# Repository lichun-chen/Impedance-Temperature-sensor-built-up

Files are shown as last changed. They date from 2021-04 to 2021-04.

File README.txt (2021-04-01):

//This project is the Final version code used in Z_T_sensor
The Z_T_sensor is designed to monitor the impedance and temperature of mortar samples installed in the field environments. Several multiplers, a real-time colock, a SD card is embaded into this circuit to get the real-time reading of the field samples.
License
OSU GENERAL PUBLIC LICENSE V1.0

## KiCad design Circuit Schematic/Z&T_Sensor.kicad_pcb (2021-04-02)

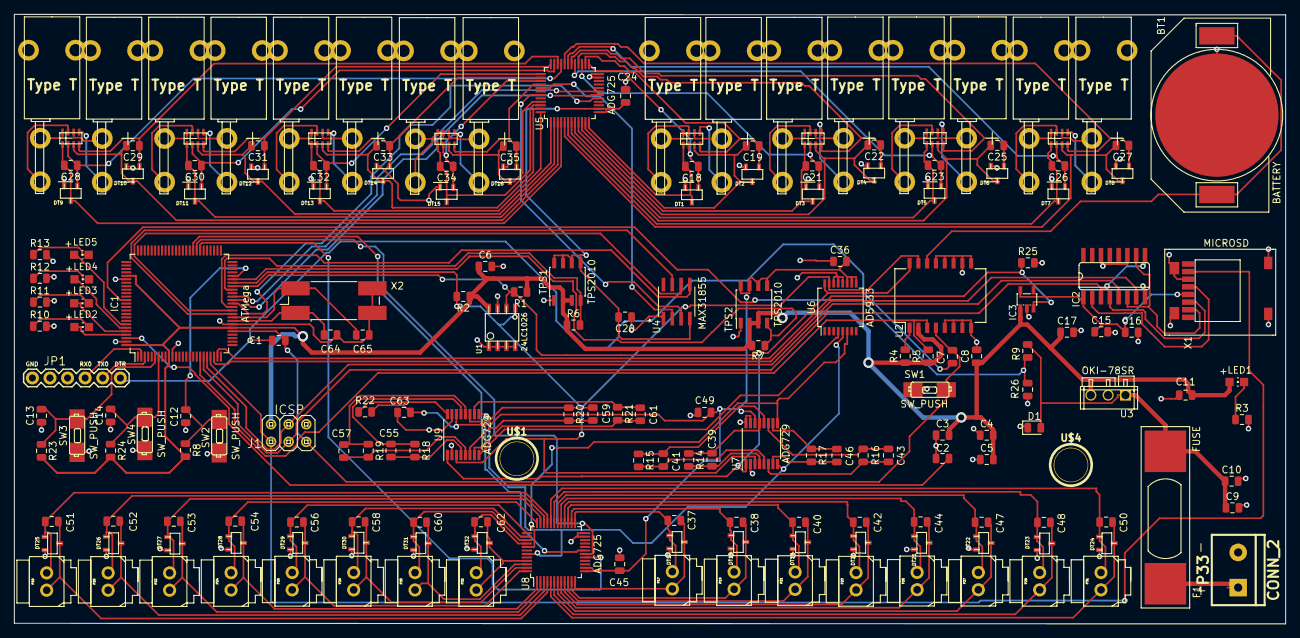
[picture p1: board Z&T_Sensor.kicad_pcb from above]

Board: 2 copper layers, 183.6 x 88.0 mm, 196 parts (0 on the bottom side), 169 nets.

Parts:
BT1: BATTERY; Battery_20mm_coincell
C1, C2, C3, C4, C5, C6, C7, C8, C12, C13, C14, C15, C17: 0.1uF; C_0805_2012Metric
C9: 10u; C_0805_2012Metric
C10, C11: 0.1u; C_0805_2012Metric
C16: 10uF; C_0805_2012Metric
C18, C19, C20, C21, C22, C23, C24, C25, C26, C27, C28, C29, C30, C31, C32, C33, C34, C35, C36, C37, C38, C39, C40, C41, C42, C43, C44, C45, C46, C47, C48, C49, C50, C51, C52, C53, C54, C55, C56, C57, C58, C59, C60, C61, C62, C63: .01uF; C_0805_2012Metric
C64, C65: 22pF; C_0805_2012Metric
D1: DIODE; D_0805_2012Metric
DT1, DT2, DT3, DT4, DT5, DT6, DT7, DT8, DT9, DT10, DT11, DT12, DT13, DT14, DT15, DT16, DT17, DT18, DT19, DT20, DT21, DT22, DT23, DT24, DT25, DT26, DT27, DT28, DT29, DT30, DT31, DT32: TVSARRAY
F1: FUSE; FUSE_5x25
FB1, FB2, FB3, FB4, FB5, FB6, FB7, FB8: FEARRAY
IC1: ATMEGA2560-A; ATMega_TQFP-100_14x14mm_P0.5mm
IC2: 4050D; SO16
IC3: LP298XS; SOT23-5L
J1: ICSP; ICSP-pinhead-1-2X03
JP1: FTDI Basic; 1X06
LED1, LED2, LED3, LED4, LED5: LED; CHIP-LED0805
P1, P2, P3, P4, P5, P6, P7, P8, P9, P10, P11, P12, P13, P14, P15, P16: CONN_4; thermocouple-connector
P17, P18, P19, P20, P21, P22, P23, P24, P25, P26, P27, P28, P29, P30, P31, P32: CONN_2; Z_COMBICON2
P33: CONN_2; bornier2_V
R1, R2, R22, R26: 10K; R_0805_2012Metric
R3, R4, R5, R10, R11, R12, R13: 330; R_0805_2012Metric
R6, R7, R25: 100K; R_0805_2012Metric
R8, R9, R23, R24: 47k; R_0805_2012Metric
R14, R18: 560; R_0805_2012Metric
R15, R19: 1000; R_0805_2012Metric
R16, R20: 1500; R_0805_2012Metric
R17, R21: 2000; R_0805_2012Metric
SW1, SW2, SW3, SW4: SW_PUSH; SWITCH_2padsmd
TPS1, TPS2: TPS2010; TPS2010_SOIC-8-N8_3.9x4.9mm_P1.27mm
U1: 24LC1026
U2: DS3231; SOIC-16W_7.5x12.8mm_P1.27mm
U3: OKI-78SR
U4: MAX31855; MAX31855TASA&plus_T
U5, U8: ADG725; ADG725_TQFP-48-1EP_7x7mm_P0.5mm_EP3.5x3.5mm
U6: AD5933; AD5933_SSOP-16_5.3x6.2mm_P0.65mm
U7, U9: ADG729; ADG729_TSSOP-16_4.4x5mm_P0.65mm
U$1, U$4: FIDUCIAL; DrillHole_1pin
X1: MICROSD; MicroSD_2
X2: CRYSTAL; Crystal_SMD_SeikoEpson_MA506-4Pin_12.7x5.1mm

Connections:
+12V: F1.1, P33.1
/MISO: IC1.22, J1.1, X1.7
/MOSI: IC1.21, IC2.5, J1.4
/RX0: IC1.2, JP1.3
/SCK: IC1.20, IC2.3, IC2.9, J1.3
/SD_CS: IC1.23, IC2.7
/SD_Card/+3V3: C15.1, C16.1, IC2.1, IC3.5, X1.4
/SD_EN: IC1.24, IC3.3, R25.1
/Switch_LED/SWITCH1: C12.2, IC1.46, R8.1, SW2.2
/Switch_LED/SWITCH2: C13.2, IC1.6, R23.1, SW3.2
/Switch_LED/SWITCH3: C14.2, IC1.7, R24.1, SW4.2
/TX0: IC1.3, JP1.2
/T_sensor/5V: C20.2, C24.1, TPS1.5, TPS1.6, TPS1.7, TPS1.8, U4.4, U5.13, U5.14
/T_sensor/DIN: IC1.39, U5.18
/T_sensor/MISO: IC1.35, U4.7
/T_sensor/SCK: IC1.37, U4.5
/T_sensor/SCLK: IC1.40, U5.19
/T_sensor/SS: IC1.36, U4.6
/T_sensor/SYNC: IC1.38, U5.17
/T_sensor/ThermocoupleBreakout/T1a: FB1.5, P1.1
/T_sensor/ThermocoupleBreakout/T1b: FB1.6, P1.2
/T_sensor/ThermocoupleBreakout/T2a: FB1.7, P3.1
/T_sensor/ThermocoupleBreakout/T2b: FB1.8, P3.2
/T_sensor/ThermocoupleBreakout/T3a: FB2.5, P5.1
/T_sensor/ThermocoupleBreakout/T3b: FB2.6, P5.2
/T_sensor/ThermocoupleBreakout/T4a: FB2.7, P7.1
/T_sensor/ThermocoupleBreakout/T4b: FB2.8, P7.2
/T_sensor/ThermocoupleBreakout/T5a: FB3.5, P9.1
/T_sensor/ThermocoupleBreakout/T5b: FB3.6, P9.2
/T_sensor/ThermocoupleBreakout/T6a: FB3.7, P11.1
/T_sensor/ThermocoupleBreakout/T6b: FB3.8, P11.2
/T_sensor/ThermocoupleBreakout/T7a: FB4.5, P13.1
/T_sensor/ThermocoupleBreakout/T7b: FB4.6, P13.2
/T_sensor/ThermocoupleBreakout/T8a: FB4.7, P15.1
/T_sensor/ThermocoupleBreakout/T8b: FB4.8, P15.2
/T_sensor/ThermocoupleBreakout/T9a: FB5.5, P2.1
/T_sensor/ThermocoupleBreakout/T9b: FB5.6, P2.2
/T_sensor/ThermocoupleBreakout/T10a: FB5.7, P4.1
/T_sensor/ThermocoupleBreakout/T10b: FB5.8, P4.2
/T_sensor/ThermocoupleBreakout/T11a: FB6.5, P6.1
/T_sensor/ThermocoupleBreakout/T11b: FB6.6, P6.2
/T_sensor/ThermocoupleBreakout/T12a: FB6.7, P8.1
/T_sensor/ThermocoupleBreakout/T12b: FB6.8, P8.2
/T_sensor/ThermocoupleBreakout/T13a: FB7.5, P10.1
/T_sensor/ThermocoupleBreakout/T13b: FB7.6, P10.2
/T_sensor/ThermocoupleBreakout/T14a: FB7.7, P12.1
/T_sensor/ThermocoupleBreakout/T14b: FB7.8, P12.2
/T_sensor/ThermocoupleBreakout/T15a: FB8.5, P14.1
/T_sensor/ThermocoupleBreakout/T15b: FB8.6, P14.2
/T_sensor/ThermocoupleBreakout/T16a: FB8.7, P16.1
/T_sensor/ThermocoupleBreakout/T16b: FB8.8, P16.2
/Z_sensor/5V: C36.2, C45.2, C49.2, C63.2, R22.2, TPS2.5, TPS2.6, TPS2.7, TPS2.8, U6.9, U6.10, U6.11, U7.14, U8.13, U8.14, U9.14
/Z_sensor/DIN: IC1.58, U8.18
/Z_sensor/SCLK: IC1.59, U8.19
/Z_sensor/SYNC: IC1.57, U8.17
/Z_sensor/z_impedance/Z1A: C37.2, DT17.2, P17.1, U8.12
/Z_sensor/z_impedance/Z1B: C37.1, DT17.1, P17.2, U8.25
/Z_sensor/z_impedance/Z2A: C38.2, DT18.2, P19.1, U8.11
/Z_sensor/z_impedance/Z2B: C38.1, DT18.1, P19.2, U8.26
/Z_sensor/z_impedance/Z3A: C40.2, DT19.2, P21.1, U8.10
/Z_sensor/z_impedance/Z3B: C40.1, DT19.1, P21.2, U8.27
/Z_sensor/z_impedance/Z4A: C42.2, DT20.2, P23.1, U8.9
/Z_sensor/z_impedance/Z4B: C42.1, DT20.1, P23.2, U8.28
/Z_sensor/z_impedance/Z5A: C44.2, DT21.2, P25.1, U8.8
/Z_sensor/z_impedance/Z5B: C44.1, DT21.1, P25.2, U8.29
/Z_sensor/z_impedance/Z6A: C47.2, DT22.2, P27.1, U8.7
/Z_sensor/z_impedance/Z6B: C47.1, DT22.1, P27.2, U8.30
/Z_sensor/z_impedance/Z7A: C48.2, DT23.2, P29.1, U8.6
/Z_sensor/z_impedance/Z7B: C48.1, DT23.1, P29.2, U8.31
/Z_sensor/z_impedance/Z8A: C50.2, DT24.2, P31.1, U8.5
/Z_sensor/z_impedance/Z8B: C50.1, DT24.1, P31.2, U8.32
/Z_sensor/z_impedance/Z9A: C51.2, DT25.2, P18.1, U8.4
/Z_sensor/z_impedance/Z9B: C51.1, DT25.1, P18.2, U8.33
/Z_sensor/z_impedance/Z10A: C52.2, DT26.2, P20.1, U8.3
/Z_sensor/z_impedance/Z10B: C52.1, DT26.1, P20.2, U8.34
/Z_sensor/z_impedance/Z11A: C53.2, DT27.2, P22.1, U8.2
/Z_sensor/z_impedance/Z11B: C53.1, DT27.1, P22.2, U8.35
/Z_sensor/z_impedance/Z12A: C54.2, DT28.2, P24.1, U8.1
/Z_sensor/z_impedance/Z12B: C54.1, DT28.1, P24.2, U8.36
/Z_sensor/z_impedance/Z13A: C56.2, DT29.2, P26.1, U8.48
/Z_sensor/z_impedance/Z13B: C56.1, DT29.1, P26.2, U8.37
/Z_sensor/z_impedance/Z14A: C58.2, DT30.2, P28.1, U8.47
/Z_sensor/z_impedance/Z14B: C58.1, DT30.1, P28.2, U8.38
/Z_sensor/z_impedance/Z15A: C60.2, DT31.2, P30.1, U8.46
/Z_sensor/z_impedance/Z15B: C60.1, DT31.1, P30.2, U8.39
/Z_sensor/z_impedance/Z16A: C62.2, DT32.2, P32.1, U8.45
/Z_sensor/z_impedance/Z16B: C62.1, DT32.1, P32.2, U8.40
/clock-ISP schema/INTSQW: IC1.19, R5.2, U2.3
/led/LED1: IC1.97, LED2.A
/led/LED2: IC1.96, LED3.A
/led/LED3: IC1.95, LED4.A
/led/LED4: IC1.94, LED5.A
ADBATT: IC1.87, R9.1, R26.2
DTR: C1.2, C7.2, JP1.1
GND: BT1.2, C2.2, C3.1, C4.1, C5.1, C6.2, C8.2, C9.2, C10.2, C11.2, C12.1, C13.1, C14.1, C15.2, C16.2, C17.2, C20.1, C24.2, C36.1, C45.1, C49.1, C63.1, C64.2, C65.2, D1.1, DT1.3, DT2.3, DT3.3, DT4.3, DT5.3, DT6.3, DT7.3, DT8.3, DT9.3, DT10.3, DT11.3, DT12.3, DT13.3, DT14.3, DT15.3, DT16.3, DT17.3, DT18.3, DT19.3, DT20.3, DT21.3, DT22.3, DT23.3, DT24.3, DT25.3, DT26.3, DT27.3, DT28.3, DT29.3, DT30.3, DT31.3, DT32.3, IC1.11, IC1.32, IC1.81, IC1.99, IC2.8, IC2.11, IC2.14, IC3.2, J1.6, JP1.6, P1.3, P1.4, P2.3, P2.4, P3.3, P3.4, P4.3, P4.4, P5.3, P5.4, P6.3, P6.4, P7.3, P7.4, P8.3, P8.4, P9.3, P9.4, P10.3, P10.4, P11.3, P11.4, P12.3, P12.4, P13.3, P13.4, P14.3, P14.4, P15.3, P15.4, P16.3, P16.4, P33.2, R3.2, R10.2, R11.2, R12.2, R13.2, R25.2, R26.1, SW1.1, SW2.1, SW3.1, SW4.1, TPS1.1, TPS2.1, U1.1, U1.2, U1.3, U1.4, U1.7, U2.5, U2.6, U2.7, U2.8, U2.9, U2.10, U2.11, U2.12, U2.13, U3.2, U4.1, U5.23, U5.24, U6.12, U6.13, U6.14, U7.2, U7.15, U7.16, U8.23, U8.24, U9.2, U9.15, X1.6, X1.GND1, X1.GND2, X1.GND3, X1.GND4, X2.2, X2.3
unnamed: BT1.1, U2.14
unnamed: C2.1, IC1.98
unnamed: C9.1, C10.1, D1.2, F1.2, R9.2, U3.1
unnamed: C18.1, DT1.1, FB1.2, U5.25
unnamed: C18.2, DT1.2, FB1.1, U5.12
unnamed: C19.1, DT2.1, FB1.4, U5.26
unnamed: C19.2, DT2.2, FB1.3, U5.11
unnamed: C21.1, DT3.1, FB2.2, U5.27
unnamed: C21.2, DT3.2, FB2.1, U5.10
unnamed: C22.1, DT4.1, FB2.4, U5.28
unnamed: C22.2, DT4.2, FB2.3, U5.9
unnamed: C23.1, DT5.1, FB3.2, U5.29
unnamed: C23.2, DT5.2, FB3.1, U5.8
unnamed: C25.1, DT6.1, FB3.4, U5.30
unnamed: C25.2, DT6.2, FB3.3, U5.7
unnamed: C26.1, DT7.1, FB4.2, U5.31
unnamed: C26.2, DT7.2, FB4.1, U5.6
unnamed: C27.1, DT8.1, FB4.4, U5.32
unnamed: C27.2, DT8.2, FB4.3, U5.5
unnamed: C28.1, DT9.1, FB5.2, U5.33
unnamed: C28.2, DT9.2, FB5.1, U5.4
unnamed: C29.1, DT10.1, FB5.4, U5.34
unnamed: C29.2, DT10.2, FB5.3, U5.3
unnamed: C30.1, DT11.1, FB6.2, U5.35
unnamed: C30.2, DT11.2, FB6.1, U5.2
unnamed: C31.1, DT12.1, FB6.4, U5.36
unnamed: C31.2, DT12.2, FB6.3, U5.1
unnamed: C32.1, DT13.1, FB7.2, U5.37
unnamed: C32.2, DT13.2, FB7.1, U5.48
unnamed: C33.1, DT14.1, FB7.4, U5.38
unnamed: C33.2, DT14.2, FB7.3, U5.47
unnamed: C34.1, DT15.1, FB8.2, U5.39
unnamed: C34.2, DT15.2, FB8.1, U5.46
unnamed: C35.1, DT16.1, FB8.4, U5.40
unnamed: C35.2, DT16.2, FB8.3, U5.45
unnamed: C39.1, R14.2, U7.4
unnamed: C39.2, R14.1, U7.13
unnamed: C41.1, R15.2, U7.5
unnamed: C41.2, R15.1, U7.12
unnamed: C43.1, R16.2, U7.6
unnamed: C43.2, R16.1, U7.11
unnamed: C46.1, R17.2, U7.7
unnamed: C46.2, R17.1, U7.10
unnamed: C55.1, R18.2, U9.4
unnamed: C55.2, R18.1, U9.13
unnamed: C57.1, R19.2, U9.5
unnamed: C57.2, R19.1, U9.12
unnamed: C59.1, R20.2, U9.6
unnamed: C59.2, R20.1, U9.11
unnamed: C61.1, R21.2, U9.7
unnamed: C61.2, R21.1, U9.10
unnamed: C64.1, IC1.33, X2.1
unnamed: C65.1, IC1.34, X2.4
unnamed: IC1.42, R6.2, TPS1.4
unnamed: IC1.45, R7.2, TPS2.4
unnamed: IC2.2, X1.5
unnamed: IC2.4, X1.3
unnamed: IC2.6, IC2.10, X1.2
unnamed: LED1.C, R3.1
unnamed: LED2.C, R10.1
unnamed: LED3.C, R11.1
unnamed: LED4.C, R12.1
unnamed: LED5.C, R13.1
unnamed: R4.2, U2.1
unnamed: R22.1, U9.16
unnamed: U4.2, U5.41
unnamed: U4.3, U5.43
unnamed: U6.4, U9.8
unnamed: U6.5, U7.8, U8.43, U9.9
unnamed: U6.6, U7.9, U8.41
RESET: C1.1, C7.1, IC1.30, J1.5, SW1.2, U2.4
SCL: IC1.43, R1.2, U1.6, U2.16, U6.16, U7.1, U9.1
SDA: IC1.44, R2.2, U1.5, U2.15, U6.15, U7.3, U9.3
V1: C3.2, C4.2, C5.2, C6.1, C8.1, C11.1, C17.1, IC1.10, IC1.31, IC1.80, IC1.100, IC3.1, J1.2, LED1.A, R1.1, R2.1, R4.1, R5.1, R6.1, R7.1, R8.2, R23.2, R24.2, TPS1.2, TPS1.3, TPS2.2, TPS2.3, U1.8, U2.2, U3.3

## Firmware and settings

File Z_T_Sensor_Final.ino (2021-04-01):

//*******************************************************************************************************************************************
#include "AD5933.h"
#include "Adafruit_MAX31855.h"
#include <Wire.h>
#include <SD.h>
#include <SPI.h>
#include "Z_T_functions.h"

//*******************************************************************************************************************************************
//******************************************DEFINE Z&T measurement part**********************************************************************
Adafruit_MAX31855 THERMOcouple(MAXCLK, MAXCS, MAXDO);
Z_T_functions_Class Z_T_func;

//*******************************************************************************************************************************************
//******************************************DEFINE ADG725 code*******************************************************************************
int pinoff=128;//code to turn off all the switches of ADG725 (16 ports)
int SWITCHnum = 0;
int CALIBnum = 1;

//*******************************************************************************************************************************************
//******************************************DEFINE Battery part******************************************************************************
int BATT_VOLT = 0;

//*******************************************************************************************************************************************
//*******************************************************************************************************************************************
void setup()
{
  Wire.begin();        // join i2c bus (address optional for master)   
  Serial.begin(9600);
  while (!Serial) delay(1); // wait for Serial on Leonardo/Zero, etc

  //set the pins for LEDS
  pinMode(LED2, OUTPUT);
  pinMode(LED3, OUTPUT);
  pinMode(LED4, OUTPUT);
  pinMode(LED5, OUTPUT);
  digitalWrite(LED2, LOW);
  digitalWrite(LED3, LOW);
  digitalWrite(LED4, LOW);
  digitalWrite(LED5, LOW);
  
  //set pin mode for multiplexers_resistors
  pinMode(SS_Z, OUTPUT);
  pinMode(SCLK_Z, OUTPUT); 
  pinMode(MOSI_Z, OUTPUT);
  //set the pin mode for multiplexer_temperature
  pinMode(SS_T, OUTPUT);
  pinMode(SCLK_T, OUTPUT); 
  pinMode(MOSI_T, OUTPUT);
  
  //SD Card Initialization
  pinMode(SDCard_EN,OUTPUT);// enable voltage converter (define as asigned in the KiCAD file)
  digitalWrite(SDCard_EN, HIGH);// enable voltage converter (define as asigned in the KiCAD file)
  pinMode(SD_CS,OUTPUT); 
  //SD card can be only initialized once, multiple initializations result to failure. so must leave this part in the setup function, not in the loop function.
  if (!SD.begin(SD_CS))
    { // if the SD card is not put right, then do nothing
      Serial.println("SD Card Initialization Failed!"); 
      digitalWrite(LED4,HIGH); // Turn on the LED4 as a sign for SD card failed.
    }

  //set TPS2010 EN pin
  pinMode(TPSEN_Z, OUTPUT);
  pinMode(TPSEN_T, OUTPUT);
  //TUEN OFF THE TPS2010 SWITCH at the setup beginning
  digitalWrite(TPSEN_Z, HIGH); // LOW turns on the power; High turns off the power
  digitalWrite(TPSEN_T, HIGH); // LOW turns on the power; High turns off the power
  
  delay(100);
}
//*****************************************************************************************************************************************************
void loop()
{
  // GET THE VOLTAGE OF THE BATTERY AT THE BEGINNING OF EACH LOOP
  BATT_VOLT = Z_T_func.Batt_analogread();
  if (BATT_VOLT < Batt_Low) // if the battery is low then do nothing
  {delay(1800000); /*delay 30mins */ }
  else {     
      //****************************************************************************************************************************************************
      //Turn on TPS2010 switch. set the EN pin for TPSEN_Z, TPSEN_T
      digitalWrite(TPSEN_Z, LOW); // LOW turns on the power; High turns off the power
      digitalWrite(TPSEN_T, LOW); // LOW turns on the power; High turns off the power
              
      //close all switch pins of ADG729 before measurement
      Z_T_func.SwiChoi_Z(0, ADDRESS_SwiCalib);// close all switch pins of impedance calibration
      Z_T_func.SwiChoi_Z(0, ADDRESS_SwiRFB);// close all switch pins of RFB resistor
      //close all switch pins of ADG725 (16 ports) before measurement
      Z_T_func.Switch_Z(pinoff);
      Z_T_func.Switch_T(pinoff);
  
      // set the initial time here:only run this part once
      // NOTE: This part must be put after the function of an I2C device (ADG729 here), otherwise the clock will not work
      // DS3231 seconds, minutes, hours, day, date, month, year
      //Z_T_func.setDS3231time(30,57,17,1,25,8,19); 
            
      //Turn off all the LEDS befores measurement. start measuring impedance&temperature SIGN
      digitalWrite(LED2,LOW);
      digitalWrite(LED3,LOW);
      digitalWrite(LED4,LOW);
      digitalWrite(LED5,LOW);
      //************************************Measure Battery ***********************************************************************************************
      Z_T_func.Batt_Volt();
      //************************************Measure Impedance***********************************************************************************************    
      // start measure the calibration resistors
      for (CALIBnum = 1; CALIBnum <5; CALIBnum ++){
          Z_T_func.SwiChoi_Z(CALIBnum, ADDRESS_SwiCalib);
          Z_T_func.impeTest(0,CALIBnum, LED2);//LED2 will blink when it is measuring
      }
      //close all pins of calibration ports
      Z_T_func.SwiChoi_Z(0, ADDRESS_SwiCalib); // close all switch pins of impedance calibration
              
      // start measure impedance with different switchnum.
      for (SWITCHnum = 0; SWITCHnum < 16; SWITCHnum ++) {  
          Z_T_func.Switch_Z(SWITCHnum);
          Z_T_func.impeTest(1, SWITCHnum, LED2);//LED2 will blink when it is measuring
      }
      //close all pins of switch_resistor
      Z_T_func.Switch_Z(pinoff);
              
      delay(100);//delay 0.1s
      //***********************************Measure Temperature**********************************************************************************************
      // start measure temperature with different switchnum.
      for (SWITCHnum = 0; SWITCHnum <8 ; SWITCHnum ++) {
          Z_T_func.Switch_T(SWITCHnum);
          Z_T_func.tempTest(SWITCHnum, LED2, THERMOcouple); // LED2 will blink when it is measuring
      }
      //close all pins of switch_temperature
      Z_T_func.Switch_T(pinoff);
              
      delay(100);//delay 0.1s
      //****************************************************************************************************************************************************
      //TUEN OFF THE TPS2010 SWITCH AFTER MEASUREMENT
      digitalWrite(TPSEN_Z, HIGH); // LOW turns on the power; High turns off the power
      digitalWrite(TPSEN_T, HIGH); // LOW turns on the power; High turns off the power
      
      delay(1800000); //delay 30mins
       
  }
}

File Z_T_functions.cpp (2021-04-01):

#include "Z_T_functions.h"
#include "Adafruit_MAX31855.h"
#include <SD.h>
#include <Arduino.h> // For the compatibility with Arduino Conventions.

//*******************************************Impedance Measurement Part*********************************************************************************************
//******************************************************************************************************************************************************************
// Switch change function of switch_calibration & switch_reference
void Z_T_functions_Class::SwiChoi_Z(int i, byte ADDRESS){
    int VAL[5] = {0,17,34,68,136}; // represent: off all, open S1A&S1B:560ohm, open S2A&S2B:1000ohm, open S3A&S3B:1500ohm, open S4A&S4B:2000ohm, 
    Wire.beginTransmission(ADDRESS); //transmit to device 
    byte val = VAL[i];
    Serial.println(val);
    Wire.write(val);
    Wire.endTransmission(); // stop transmitting
    delay(100);      
    return;
}

// Switch change function of Switch_resistors
void Z_T_functions_Class::Switch_Z(int j){
  digitalWrite(SS_Z, LOW); 
  shiftOut(MOSI_Z, SCLK_Z, MSBFIRST, j);
  digitalWrite(SS_Z, HIGH);
  delay(100);
  return;
}

// impedance measure function
void Z_T_functions_Class::impeTest(int calibOR_, int switchnum, int led){ 
    File file;
    String filename;
    filename_date(&filename);// get the filename based on the date
    Serial.println(filename);      
    file = SD.open(filename, FILE_WRITE);
     
    displaytime(file);
    switch(calibOR_){
      case 0: {
        Serial.print("Calibration sample_value:");  Serial.print("\t");  
        Serial.print(calibnum_Z[switchnum]);  Serial.print("\t");
        Serial.println(calibvalue_Z[switchnum]);   
        if(file){
          file.print("Calibration sample_value:"); file.print("\t");
          file.print(calibnum_Z[switchnum]); file.print("\t");
          file.println(calibvalue_Z[switchnum]);          
        } else {Serial.println("error opening file"); digitalWrite(LED4,HIGH);/* Turn on the LED4 as a sign of SD card fail */  return;}
        break;
      }
      case 1: {
        Serial.print("impedance sample_layer:");  Serial.print("\t");  
        Serial.print(samplenum_Z[switchnum]);  Serial.print("\t");
        Serial.println(level_Z[switchnum]);   
        if(file){
          file.print("impedance sample_layer:"); file.print("\t");
          file.print(samplenum_Z[switchnum]); file.print("\t");
          file.println(level_Z[switchnum]);          
        } else {Serial.println("error opening file"); digitalWrite(LED4,HIGH);/* Turn on the LED4 as a sign of SD card fail */  return;}
        break;
      }
    } 

    // test with the RFB = 560ohm first
    SwiChoi_Z(1, ADDRESS_SwiRFB);// 1,2,3,4 represent S1A&S1B:560ohm,S2A&S2B:1000ohm,S3A&S3B:1500ohm,S4A&S4B:2000ohm
    double gainfactor = gainfactor_560;
    double pshift = pshift_560;
    AD5933.setExtClock(false); //Write Bit D3 in control register 0x81.
    AD5933.resetAD5933(); //Set the reset Bit D4 in control register 0x81.
    AD5933.setStartFreq(start_frequency);//Write in start frequency register 0x82, 0x83, 0x84.
    //Cycles to ignore before a measurement is taken. Max is 511.
    AD5933.setSettlingCycles(cycles_base, cycles_multiplier);//Write in Number of setting time cycles register 0x8A, 0x8B.   
    AD5933.setStepSizeInHex(1);// Write in frequency increment register 0x85, 0x86, 0x87.
    AD5933.setNumofIncrement(2);// Write in number of increments register 0x88,0x89.
    AD5933.setPGA(GAIN_1);//Write the D8 bit to set PGA gain in control register 0x80,0=*5,1=*1.
    AD5933.setRange(RANGE_1);// write the bit D9 & D10 to set range no. in control register 0x80.
    AD5933.setCtrMode(STAND_BY); //set standby mode0
    AD5933.setCtrMode(INIT_START_FREQ); //initialize with start frequency
   
    int a=millis();
    while(((millis()-a)/1000-10)<set_time);//-10 is for let it wait until the AD5933 chip sets. MUST!   
    AD5933.setCtrMode(START_FREQ_SWEEP);//start frequency sweep  
    while ( (AD5933.getStatusReg() & 0x02) != 0x02 ); // Wait until measurement is complete. 

    int n=0;
    double Z_Val, phase;
//*********************************************Measure impedance for the 1st time to see whether the impedance is over 2200ohm or not **********************************************************
    //led SIGN
    digitalWrite(led, HIGH);
    delay(200);
    digitalWrite(led, LOW);

    AD5933.tempUpdate();
    AD5933.setCtrMode(REPEAT_FREQ);//Repeat frequency sweep, so we can retest the impedence in the certain time period. Otherwise the test result will maintain the same during the time period
    while ( (AD5933.getStatusReg() & 0x02) != 0x02 ); // Wait until measurement is complete.
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

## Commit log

2021-04-01 Z_T_sensor development
    This is a sensor design project which combines AD5933 and MAX31855 with multiplexers. This sensor is designed to monitor the impedance and temperature of the mortar sample under filed environments.
2021-04-01 schematics of the circuit board
2021-04-02 Create Circuit Schematic

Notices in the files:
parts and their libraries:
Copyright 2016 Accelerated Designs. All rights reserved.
